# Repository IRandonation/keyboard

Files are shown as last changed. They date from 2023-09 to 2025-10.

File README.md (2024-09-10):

# keyboard

try to design my personal keyboard

## ROCK NUMBER KWYBOARD

### PCB design

###### ---------------2023.6.10--------------

As mt first keyboard, i try to design a small keyborad for number zone.
Not as same as regular keyboard, i tend to use stm32 instead of atmage.

###### ---------------2024.9.9----------------

Finish my PCB and successfully weld that. But what is so stupid is that i welded my shaft seat upside down, which led to i cannot put my shaft to my PCB. So i have to correct this problem.

###### ---------------2024.9.10---------------

i found a promblem that when you try to connnet stm32f103 to your computer by type-c, you should use two 5.1kR resistances in CC pin, which help computer to recognize the chip. For this version i did not use these resistance. Besides, you should use a 1.5k, which connects between D+ and 3.3V
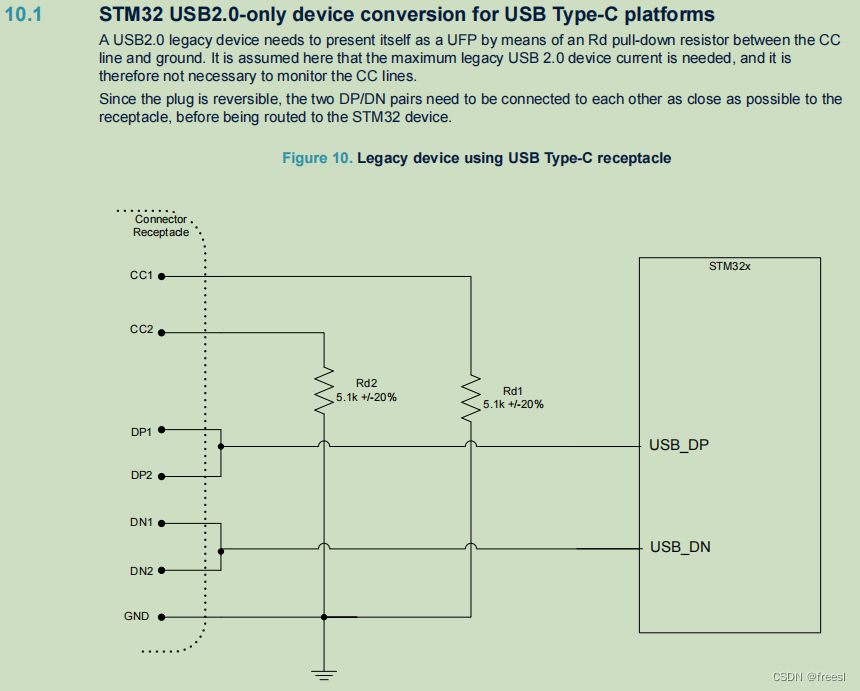
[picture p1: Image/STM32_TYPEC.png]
STM32-TYPEC

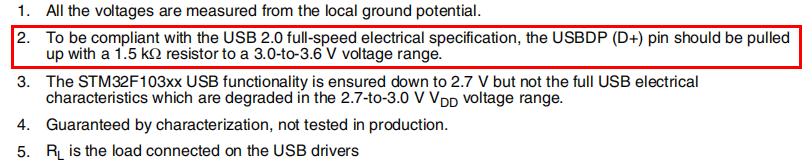
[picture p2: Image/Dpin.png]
STM32-TYPEC-D+


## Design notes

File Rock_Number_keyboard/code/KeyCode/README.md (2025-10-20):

# Rock Number Keyboard / KeyCode 项目说明

本仓库为基于 STM32F4（STM32F407）与 USB HID 的矩阵键盘固件工程，提供矩阵键盘扫描、按键映射与通过 USB 作为键盘设备向主机发送按键的能力。工程主要使用 STM32 HAL 库，配套 Keil MDK-ARM 工程文件，并保留 STM32CubeMX 的 `KeyCode.ioc` 以便后续外设与引脚配置维护。

## 功能特性
- 矩阵键盘扫描与去抖动处理（`Core/Src/matrix_keyboard.c`）
- 按键映射与事件上报（可在 `matrix_keyboard.h/.c` 中调整）
- 通过 USB 设备枚举为键盘（HID），向主机发送按键报告
- **WS2812 RGB背光系统**（`Core/Src/ws2812.c`）
  - 6种背光模式：关闭、静态、呼吸、彩虹、按键响应、波浪
  - Num Lock长按切换模式，亮度可调
  - DMA驱动，高效稳定的LED控制
  - 实时动态效果处理
- 采用 STM32 HAL 驱动与 ST 官方 USB Device Library

## 目录结构
- `Core/Inc` / `Core/Src`：应用入口与业务逻辑
  - `main.c`：程序入口与系统初始化
  - `matrix_keyboard.h/.c`：矩阵键盘扫描、映射与接口
  - `ws2812.h/.c`：WS2812 RGB背光驱动与多模式控制
  - `tim.c/h`：定时器配置（TIM4用于WS2812 PWM+DMA）
  - `gpio.c/h`：GPIO 引脚初始化
  - `stm32f4xx_it.c/h`：中断处理（包含DMA中断）
- `USB_DEVICE`：USB 设备层
  - `App/usb_device.*`：USB 栈初始化入口
  - `App/usbd_desc.*`：USB 设备描述符（VID/PID、字符串等）
  - `Target/usbd_conf.*`：与 HAL 的适配层
- `Drivers/STM32F4xx_HAL_Driver`、`Drivers/CMSIS`：HAL 与 CMSIS 依赖
- `MDK-ARM`：Keil uVision 工程（`KeyCode.uvprojx`、`KeyCode.uvoptx`）与启动文件
- `.eide`、`.vscode`：EIDE 与 VS Code 相关配置（可选）
- `KeyCode.ioc`：CubeMX 工程文件（用于生成/维护外设与引脚配置）

## 开发环境
- 工具链：
  - Keil MDK-ARM（推荐，已提供完整工程）
  - 或 STM32CubeIDE（可依据 `KeyCode.ioc` 重新生成工程后迁移代码）
- 依赖：
  - STM32F4 HAL Driver（已包含在 `Drivers` 目录）
  - ST USB Device Library（`Middlewares/ST/STM32_USB_Device_Library`）
- 目标芯片：STM32F407（参考启动文件 `startup_stm32f407xx.s`）

## 快速开始
1. 使用 Keil uVision 打开 `MDK-ARM/KeyCode.uvprojx`。
2. 连接硬件：
   - STM32F407 开发板 + 矩阵键盘
   - WS2812 LED灯带连接到 PB6 (TIM4_CH1)
   - USB设备口接PC
3. 选择正确的目标、下载器与时钟设置后，编译并烧录固件。
4. 上电后设备将枚举为 USB 键盘；按下矩阵键盘上的按键，主机应能收到对应键值。
5. **背光控制**：长按 Num Lock 键（>1秒）可切换背光模式。

## 配置说明
- 键盘矩阵与引脚：
  - 在 `Core/Inc/matrix_keyboard.h` 与 `Core/Src/gpio.c` 中查看/调整行列引脚定义与模式（上拉/输出等）。
  - 根据实际硬件连线更新对应的 GPIO 端口与引脚。
- 按键映射：
  - 在 `matrix_keyboard.c` 中维护从（行、列）到键值的映射表；可根据需求映射为数字、功能键或自定义 HID 键码。
- **WS2812背光配置**：
  - 在 `Core/Inc/ws2812.h` 中配置LED数量（`WS2812_LED_COUNT`）和引脚连接
  - 默认使用 PB6 (TIM4_CH1) 作为数据输出引脚
  - 可在 `ws2812.c` 中调整颜色、亮度、效果速度等参数
  - 支持的背光模式：OFF、STATIC、BREATHING、RAINBOW、KEY_REACTIVE、WAVE
- USB 描述符：
  - 在 `USB_DEVICE/App/usbd_desc.c` 中配置 `VID/PID`、制造商/产品字符串；如需产品化请申请合法 VID/PID。
  - HID 报告描述符位于 USB HID 类实现中（通常在 USB 类文件或键盘报告生成处维护）。如需修改键盘布局或支持组合键，需同步调整报告格式与发送逻辑。

## 运行时行为
- 系统初始化后启动矩阵扫描定时逻辑（或在主循环中轮询）。
- 按键状态变化将转换为 HID 报告并通过 USB 发送至主机。
- **WS2812背光系统**：
  - 系统启动时初始化为静态白色背光模式，亮度50%
  - 主循环中持续调用 `WS2812_ProcessEffects()` 处理动态效果
  - Num Lock键长按检测（>1秒）触发模式切换
  - 按键事件同步通知背光系统，实现按键响应效果
  - DMA传输完成后自动更新LED显示
- 去抖动、长按/重复等策略可在 `matrix_keyboard.c` 中扩展。

## 常用开发建议
- 使用 CubeMX 调整外设或引脚：
  - 打开 `KeyCode.ioc`，修改后仅生成驱动层，避免覆盖 `matrix_keyboard.*` 与业务逻辑文件。
- VS Code/EIDE：
  - 仓库提供 `.vscode/tasks.json` 与 `.eide`，可参考进行编译或工程管理（以实际环境为准）。

## 故障排查
- 设备未能枚举为键盘：
  - 检查 USB 供电与 D+/D- 连接；确认 `usb_device_init()` 被调用。
  - 确认 `usbd_conf.c` 与时钟配置（`system_stm32f4xx.c`）正确。
- 按键无响应或乱码：
  - 校验矩阵行列引脚配置与上拉/下拉设置；检查去抖动逻辑。
  - 检查按键映射是否与 HID 报告格式一致。
- **WS2812背光问题**：
  - LED不亮：检查 PB6 引脚连接，确认 TIM4 时钟使能，检查DMA配置
  - 颜色异常：确认WS2812时序参数（0码、1码脉宽），检查供电电压（5V推荐）
  - 模式切换无效：确认Num Lock键映射正确，检查长按检测逻辑
  - 效果卡顿：检查主循环中 `WS2812_ProcessEffects()` 调用频率
  - DMA传输错误：确认DMA中断处理函数 `DMA1_Stream0_IRQHandler()` 正确实现

## 示例电路连接图

### 矩阵键盘连接
- 行（输出，推挽，高速）：`GPIOE` — `PE15(R0)`, `PE14(R1)`, `PE13(R2)`, `PE12(R3)`, `PE11(R4)`。
- 列（输入，下拉）：`GPIOA` — `PA7(C0)`, `PA6(C1)`, `PA5(C2)`, `PA4(C3)`。
- 连接方式：每个交点为一个按键开关，可选串接二极管（建议 `1N4148`）以减少按键串扰与"鬼键"。推荐二极管方向：`Row →|— Diode —→ Column`（行拉高时，闭合将列拉至高电平）。

### WS2812 LED背光连接
- **数据线**：PB6 (TIM4_CH1) → WS2812 DIN
- **电源**：5V → WS2812 VDD，GND → WS2812 GND
- **布局建议**：LED按键盘布局排列，每个按键对应一个LED
- **信号完整性**：数据线尽量短，可加33Ω-100Ω串联电阻减少反射

```
Columns:   C0(PA7)    C1(PA6)    C2(PA5)    C3(PA4)
Rows
R0(PE15) ──[SW]───────[SW]───────[SW]───────[SW]
R1(PE14) ──[SW]───────[SW]───────[SW]───────(空)
R2(PE13) ──[SW]───────[SW]───────[SW]───────[SW]
R3(PE12) ──[SW]───────[SW]───────[SW]───────(空)
R4(PE11) ──[SW]───────[SW]───────[SW]───────(空)
```

说明：行由固件轮询依次拉高，列为下拉输入；当某行与某列的开关闭合时，该列读取为高电平，触发对应按键事件。

## 按键映射表（与 `matrix_keyboard.c` 保持一致）
- 行索引与引脚：`R0=PE15`, `R1=PE14`, `R2=PE13`, `R3=PE12`, `R4=PE11`
- 列索引与引脚：`C0=PA7`, `C1=PA6`, `C2=PA5`, `C3=PA4`

| 行(R) | 列(C) | 行引脚 | 列引脚 | HID 键码 | 说明 |
|---|---|---|---|---|---|
| R0 | C0 | PE15 | PA7 | `0x53` | Num Lock |
| R0 | C1 | PE15 | PA6 | `0x54` | Keypad `/` |
| R0 | C2 | PE15 | PA5 | `0x55` | Keypad `*` |
| R0 | C3 | PE15 | PA4 | `0x56` | Keypad `-` |
| R1 | C0 | PE14 | PA7 | `0x59` | Keypad `1` |
| R1 | C1 | PE14 | PA6 | `0x5A` | Keypad `2` |
| R1 | C2 | PE14 | PA5 | `0x5B` | Keypad `3` |
| R1 | C3 | PE14 | PA4 | `0x00` | 空位 |
| R2 | C0 | PE13 | PA7 | `0x5C` | Keypad `4` |
| R2 | C1 | PE13 | PA6 | `0x5D` | Keypad `5` |
| R2 | C2 | PE13 | PA5 | `0x5E` | Keypad `6` |
| R2 | C3 | PE13 | PA4 | `0x57` | Keypad `+` |
| R3 | C0 | PE12 | PA7 | `0x5F` | Keypad `7` |
| R3 | C1 | PE12 | PA6 | `0x60` | Keypad `8` |
| R3 | C2 | PE12 | PA5 | `0x61` | Keypad `9` |
| R3 | C3 | PE12 | PA4 | `0x00` | 空位 |
| R4 | C0 | PE11 | PA7 | `0x62` | Keypad `0` |
| R4 | C1 | PE11 | PA6 | `0x63` | Keypad `.` |
| R4 | C2 | PE11 | PA5 | `0x58` | Keypad `Enter` |
| R4 | C3 | PE11 | PA4 | `0x00` | 空位 |

提示：如需更改布局或引脚，请同步更新 `Core/Src/matrix_keyboard.c` 中的 `ROW_Port/ROW_Pin`、`COL_Port/COL_Pin` 与 `Key_Map`，并确保 USB HID 报告的生成逻辑能够正确处理新的键码。

## WS2812 背光模式详细说明

### 支持的背光模式

1. **OFF模式** - 所有LED关闭，节能模式
2. **STATIC模式** - 静态白色背光，适合日常使用
3. **BREATHING模式** - 呼吸灯效果，亮度平滑变化（周期约2秒）
4. **RAINBOW模式** - 彩虹色循环效果，色彩丰富动态
5. **KEY_REACTIVE模式** - 按键响应模式，按下时LED亮起，释放后渐变熄灭
6. **WAVE模式** - 青色波浪效果，从左到右流动

### 模式切换操作

- **切换方法**：长按 Num Lock 键超过1秒
- **切换顺序**：OFF → STATIC → BREATHING → RAINBOW → KEY_REACTIVE → WAVE → OFF（循环）
- **状态保持**：模式切换后立即生效，重启后恢复默认STATIC模式

### 技术参数

- **LED数量**：20个（可在 `ws2812.h` 中的 `WS2812_LED_COUNT` 修改）
- **默认亮度**：50%（可通过 `WS2812_SetBrightness()` 调节0-100%）
- **更新频率**：主循环调用，约1kHz
- **DMA传输**：使用DMA1 Stream0，自动传输24位RGB数据
- **时序标准**：符合WS2812B规范（T0H=0.4μs, T1H=0.8μs, T0L=0.85μs, T1L=0.45μs）

### API接口说明

```c
// 模式控制
void WS2812_SetMode(WS2812_Mode mode);          // 设置背光模式
WS2812_Mode WS2812_GetMode(void);               // 获取当前模式
void WS2812_NextMode(void);                     // 切换到下一个模式

// 亮度控制
void WS2812_SetBrightness(uint8_t brightness);  // 设置亮度(0-100)
uint8_t WS2812_GetBrightness(void);             // 获取当前亮度

// 效果处理
void WS2812_ProcessEffects(void);               // 处理动态效果（主循环调用）
void WS2812_OnKeyPress(uint8_t row, uint8_t col);   // 按键按下事件
void WS2812_OnKeyRelease(uint8_t row, uint8_t col); // 按键释放事件

// 颜色控制
void WS2812_SetColor(uint16_t led_index, uint8_t r, uint8_t g, uint8_t b);
void WS2812_SetAllColor(uint8_t r, uint8_t g, uint8_t b);
void WS2812_Update(void);                       // 更新LED显示
```

### 自定义开发

如需添加新的背光模式或修改现有效果：

1. 在 `ws2812.h` 中的 `WS2812_Mode` 枚举添加新模式
2. 在 `ws2812.c` 的 `WS2812_ProcessEffects()` 函数中添加对应的处理逻辑
3. 根据需要调整颜色、速度、亮度等参数
4. 可参考现有模式的实现方式，使用定时器和数学函数创建动态效果

## 许可证
- 本项目未显式声明整体许可证；第三方依赖（HAL/USB 库）遵循各自目录下的许可文件。
- 如需开源或商用，请添加或遵循相应的许可证与合规要求。

## 贡献
- 欢迎通过 Issue 或 PR 提交改进建议与修复。
- 提交前请尽量维持代码风格与目录结构一致性。

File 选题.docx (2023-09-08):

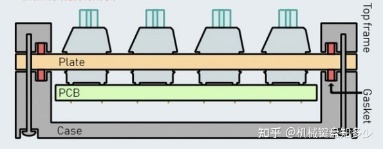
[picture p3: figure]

键盘配色：深空灰配白，铝坨坨

配重：正常

键盘结构：Gasket（比较难特别是对于硅胶垫）/top结构

铭牌：暂定

键帽：白、蓝、黑、灰

轴体：热插拔

定位板：铝定（声音沉闷）

PCB：立创定制

数据线：航插线或三模

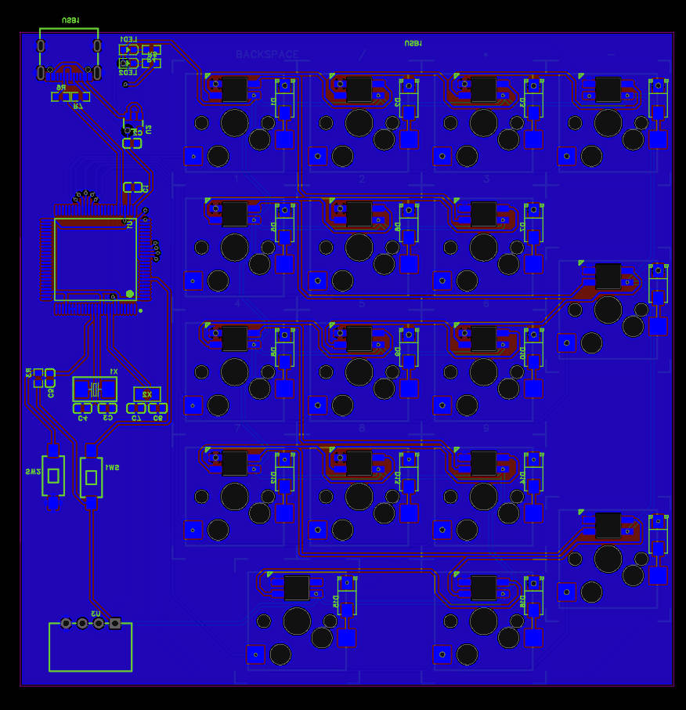
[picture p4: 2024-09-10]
Image/PCB.jpg

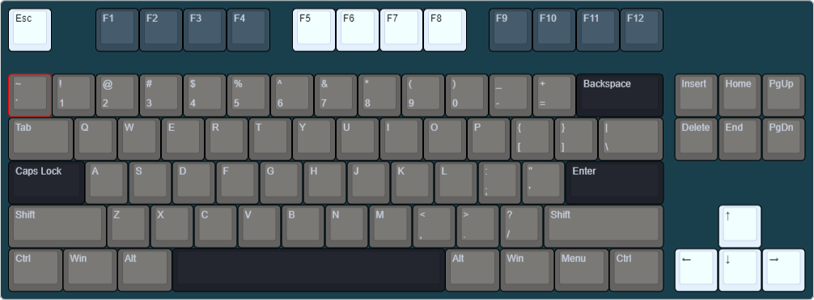
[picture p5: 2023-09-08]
Galaxy_87Keyboard/keyboard-layout.png

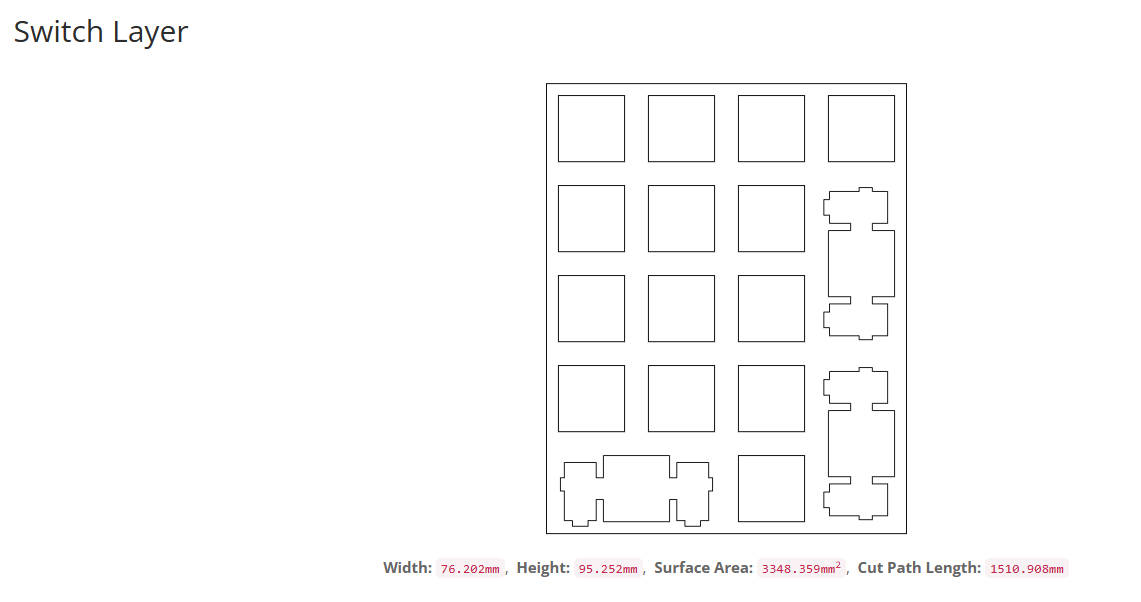
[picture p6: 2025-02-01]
Rock_Number_keyboard/keyboard.jpg

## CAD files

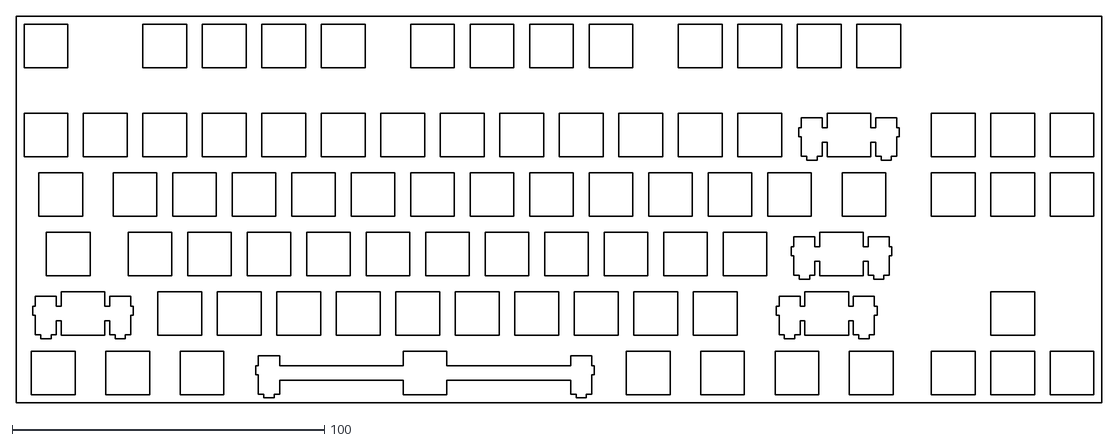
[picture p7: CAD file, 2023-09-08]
Galaxy_87Keyboard/Keyboard.dxf
347.7 x 123.8

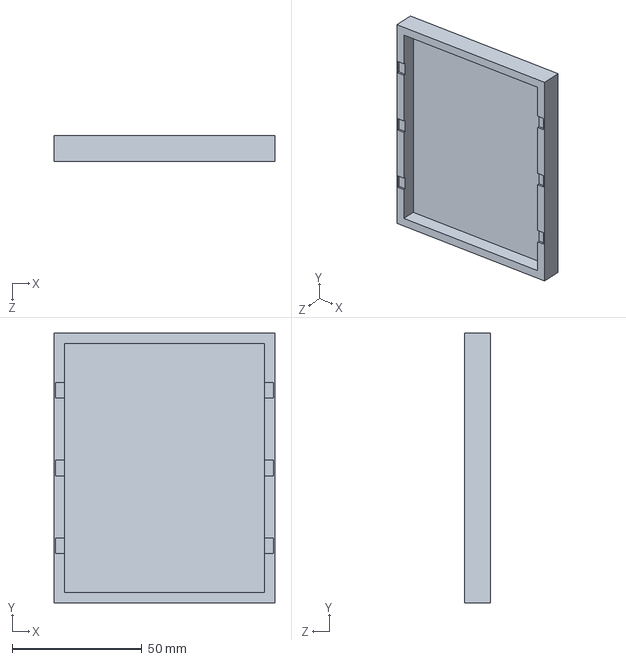
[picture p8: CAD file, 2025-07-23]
Rock_Number_keyboard/3D/外壳.SLDPRT
85.1 x 104.2 x 10.0 mm

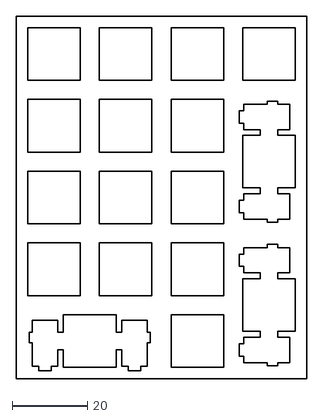
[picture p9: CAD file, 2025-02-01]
Rock_Number_keyboard/Rock_Number_pcb.dxf
77.1 x 96.2

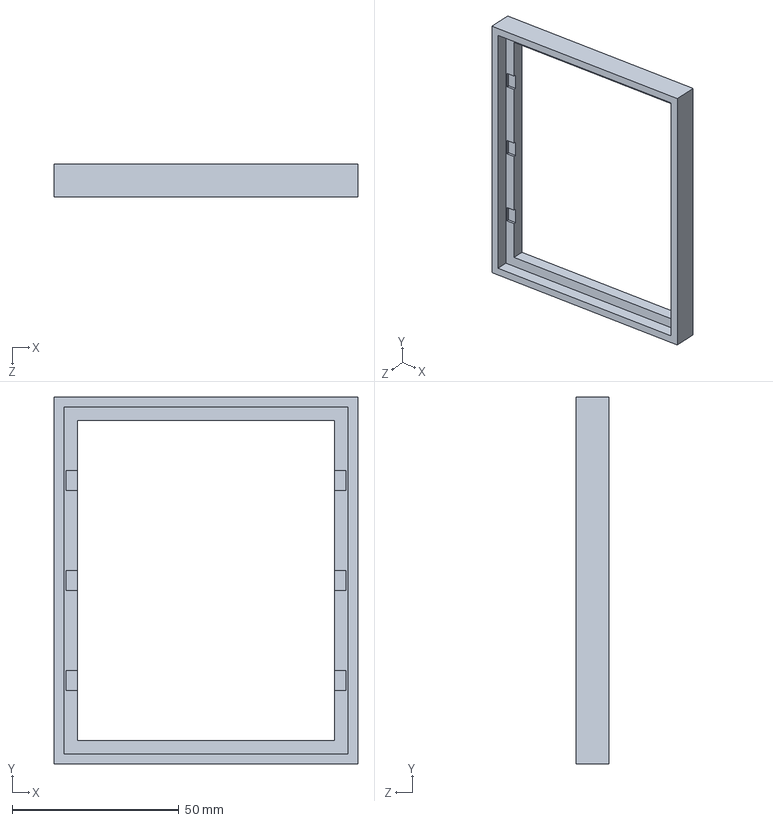
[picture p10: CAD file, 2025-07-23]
Rock_Number_keyboard/3D/上盖.SLDPRT
91.1 x 110.2 x 10.0 mm

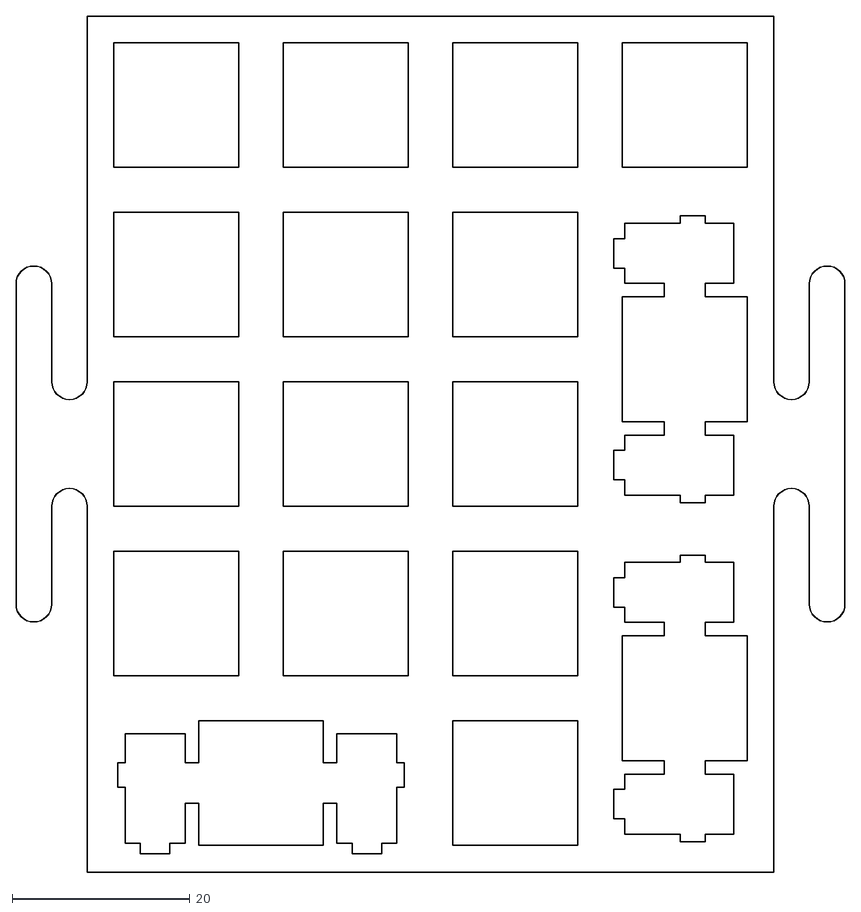
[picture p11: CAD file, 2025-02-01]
Rock_Number_keyboard/Rock_Number.dxf
93.1 x 96.2

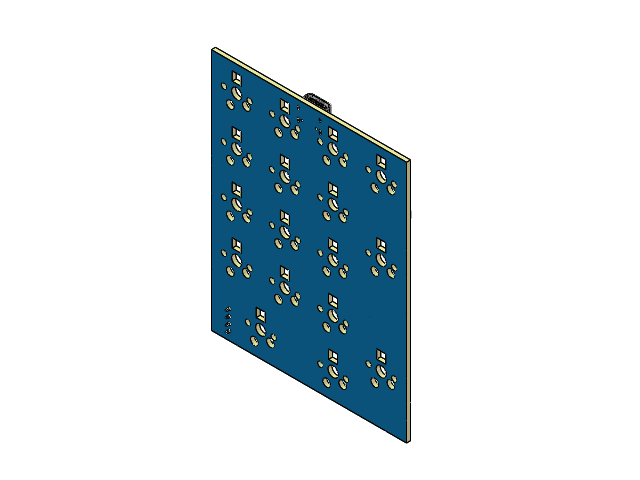
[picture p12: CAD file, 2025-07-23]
Rock_Number_keyboard/3D/PCB/3D_Rock_Number_Keyboard_2025-05-22.SLDASM
eauz-Board
eauz-C1-C0603 x 6
eauz-X1-OSC-SMD_L5.0-W3.2
eauz-SW1-SW-SMD_L6.0-W3.3-LS8.0 x 2
eauz-D1-SOD-123_L2.8-W1.6-LS3.7-RD x 17
eauz-U2-LQFP-100_L14.0-W14.0-P0.50-LS16.0-BL

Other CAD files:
Rock_Number_keyboard/3D/PCB/eauz-R1-R0603.SLDASM
Rock_Number_keyboard/3D/PCB/eauz-R5-R0603.SLDASM
Rock_Number_keyboard/3D/PCB/eauz-H1-HDR-TH_4P-P2.54-V-F.SLDASM
Rock_Number_keyboard/3D/PCB/eauz-USB1-USB-C-SMD_KH-TYPE-C-16P.SLDASM
Rock_Number_keyboard/3D/PCB/eauz-R3-R0603.SLDASM
Rock_Number_keyboard/3D/PCB/eauz-R6-R0603.SLDASM
Rock_Number_keyboard/3D/PCB/eauz-LED1-LED0603-RD_GREEN.SLDASM
Rock_Number_keyboard/3D/PCB/eauz-R7-R0603.SLDASM
Rock_Number_keyboard/3D/PCB/eauz-R4-R0603.SLDASM
Rock_Number_keyboard/3D/PCB/eauz-U1-SOT-23-5_L2.9-W1.6-P0.95-LS2.8-BR.SLDASM
Rock_Number_keyboard/3D/PCB/eauz-R2-R0603.SLDASM
Rock_Number_keyboard/3D/PCB/eauz-Board.SLDPRT
Galaxy_87Keyboard/Keyboard.dwg
Rock_Number_keyboard/3D/Board.SLDPRT
Rock_Number_keyboard/3D/PCB/COMPOUND.SLDPRT
Rock_Number_keyboard/3D/PCB/COMPOUND_2.SLDPRT
Rock_Number_keyboard/3D/PCB/COMPOUND_3.SLDPRT
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

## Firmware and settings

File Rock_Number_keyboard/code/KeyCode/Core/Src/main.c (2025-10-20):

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
/* Includes ------------------------------------------------------------------*/
#include "main.h"
#include "tim.h"
#include "usb_device.h"
#include "gpio.h"
#include "ws2812.h"

/* USER CODE BEGIN Includes */
#include "usbd_hid.h"
#include "matrix_keyboard.h"  // 包含矩阵键盘头文件
#include <stdbool.h>

/* USER CODE END Includes */


/* USER CODE BEGIN PV */
extern USBD_HandleTypeDef hUsbDeviceFS;
// HID报告结构体（兼容标准键盘）
#pragma pack(push, 1)
typedef struct {
    uint8_t modifier;   // 修饰键
    uint8_t reserved;   // 保留
    uint8_t keycode[6]; // 最多6键
} HID_KeyboardReport;
#pragma pack(pop)

// 添加键盘报告变量
static HID_KeyboardReport keyboard_report;

// 发送HID报告
void Send_HID_Report(uint8_t keycode) {
    HID_KeyboardReport report = {0};

    if (keycode != 0) {
        report.keycode[0] = keycode; // 单键按下
    }

    // 通过USB发送报告
    USBD_HID_SendReport(&hUsbDeviceFS, (uint8_t*)&report, sizeof(report));
    HAL_Delay(20); // 等待数据发送完成
}

/* USER CODE END PV */

void SystemClock_Config(void);
/**
  * @brief  The application entry point.
  * @retval int
  */
int main(void)
{
  /* MCU Configuration--------------------------------------------------------*/

  /* Reset of all peripherals, Initializes the Flash interface and the Systick. */
  HAL_Init();

  /* Configure the system clock */
  SystemClock_Config();

  /* Initialize all configured peripherals */
  MX_GPIO_Init();
  MX_USB_DEVICE_Init();
  MX_TIM3_Init();
  MX_TIM4_Init();
  /* USER CODE BEGIN 2 */
  WS2812_Init();
  HAL_TIM_Base_Start_IT(&htim3);
  MatrixKeyboard_Init();
  /* 定义一个缓冲区来接收按键事件 */
   KeyEvent key_events_buffer[MAX_PRESSED_KEYS];
   
  // 用于标记HID报告是否需要更新并发送
  bool report_needs_update = false;

  // 清空初始的键盘报告
  memset(&keyboard_report, 0, sizeof(keyboard_report));
  
  // 模式切换相关变量
  static uint32_t num_lock_press_time = 0;
  static bool num_lock_long_press_handled = false;
  
  // 设置默认背光模式
  WS2812_SetMode(WS2812_MODE_STATIC);
  WS2812_SetBrightness(50);
  
  /* USER CODE END 2 */

  /* Infinite loop */
  /* USER CODE BEGIN WHILE */
  while (1)
  {
    // 1. 从事件队列获取按键事件（由TIM3中断产生）
        uint8_t event_count = 0;
        for (uint8_t i = 0; i < MAX_PRESSED_KEYS; i++) {
            if (MatrixKeyboard_PopEvent(&key_events_buffer[i])) {
                event_count++;
            } else {
                break;
            }
        }

        // 2. 如果有任何事件发生，则处理它们
        if (event_count > 0) {
            // 标记报告需要更新
            report_needs_update = true;

            for (uint8_t i = 0; i < event_count; i++) {
                KeyEvent event = key_events_buffer[i];

                // 检查是否是Num Lock键 (ROW0, COL0, 键码0x53)
                bool is_num_lock = (event.row == 0 && event.col == 0 && event.key_code == 0x53);

                if (event.event == KEY_EVENT_PRESS) 
                {
                    if (is_num_lock) {
                        num_lock_press_time = HAL_GetTick();
                        num_lock_long_press_handled = false;
                    }
                    
                    // 按下事件: 将键码添加到HID报告中
                    // 查找一个空位来存放新的键码
                    for (int j = 0; j < 6; j++) {
                        if (keyboard_report.keycode[j] == 0x00) {
                            keyboard_report.keycode[j] = event.key_code;
                            break;
                        }
                    }
                    
                    // 通知WS2812按键按下事件
                    WS2812_OnKeyPress(event.row, event.col);
                }
                else if (event.event == KEY_EVENT_LONG_PRESS) 
                {
                    if (is_num_lock && !num_lock_long_press_handled) {
                        // Num Lock长按切换背光模式
                        WS2812_NextMode();
                        num_lock_long_press_handled = true;
                        
                        // 不发送Num Lock的HID报告，避免切换系统Num Lock状态
                        continue;
                    }
                    
                    // 其他键的长按处理
                    for (int j = 0; j < 6; j++) {
                        if (keyboard_report.keycode[j] == 0x00) {
                            keyboard_report.keycode[j] = event.key_code;
                            break;
                        }
                    }
                    
                    WS2812_OnKeyPress(event.row, event.col);
                }
                else if (event.event == KEY_EVENT_REPEAT) 
                {
                    // 连发事件处理
                    if (!is_num_lock) {  // Num Lock不处理连发
                        for (int j = 0; j < 6; j++) {
                            if (keyboard_report.keycode[j] == 0x00) {
                                keyboard_report.keycode[j] = event.key_code;
                                break;
                            }
                        }
                    }
                }
                else if (event.event == KEY_EVENT_RELEASE) 
                {
                    if (is_num_lock) {
                        uint32_t press_duration = HAL_GetTick() - num_lock_press_time;
                        
                        // 如果是短按且没有处理过长按，则正常发送Num Lock
                        if (press_duration < 1000 && !num_lock_long_press_handled) {
                            // 正常的Num Lock短按，发送HID报告
                        } else {
                            // 长按释放，不发送HID报告
                            continue;
                        }
                    }
                    
                    // 释放事件: 从HID报告中移除该键码
                    for (int j = 0; j < 6; j++) {
                        if (keyboard_report.keycode[j] == event.key_code) {
                            keyboard_report.keycode[j] = 0x00; // 清除
                        }
                    }
                    
                    // 通知WS2812按键释放事件
                    WS2812_OnKeyRelease(event.row, event.col);
                }
            }
        }

        // 3. 检查是否需要发送HID报告
        // 只有在按键状态变化时才发送，这比每次循环都发送更高效
        if (report_needs_update) {
            // 清除更新标记
            report_needs_update = false;

            // 发送HID报告（仅在状态变化时发送）
            USBD_HID_SendReport(&hUsbDeviceFS, (uint8_t*)&keyboard_report, sizeof(keyboard_report));
            
            // 为了处理按键释放，我们需要在发送完有效报告后，
            // 立即发送一个全零的 "释放" 报告。
            // 但更好的做法是让PC自己处理按键释放。
            // 只有当所有按键都释放时，我们才需要发送一个全零报告。
            // 我们可以通过检查 keyboard_report 是否全为0来判断。
            bool all_keys_released = true;
            for(int j=0; j<6; j++) {
                if (keyboard_report.keycode[j] != 0) {
                    all_keys_released = false;
                    break;
                }
            }

            // 如果所有按键都释放了，并且上一次不是全零报告，则发送一次全零报告
            if(all_keys_released){
                 // 稍作延时，确保上一个报告被PC接收
                 // HAL_Delay(1); 
                 // 发送全零报告
                 memset(&keyboard_report, 0, sizeof(keyboard_report));
                 USBD_HID_SendReport(&hUsbDeviceFS, (uint8_t*)&keyboard_report, sizeof(keyboard_report));
            }
        }

        // 处理WS2812动态效果
        WS2812_ProcessEffects();
        
        // 更新 WS2812 LED 如果有变化
        if (report_needs_update) {
            WS2812_Update();
        }
        
        // 可以在这里加一个非常短的延时，以降低CPU使用率，但不是必须的
        // HAL_Delay(1); 
    }
    /* USER CODE END WHILE */

}

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
/* USER CODE BEGIN 4 */
void HAL_TIM_PeriodElapsedCallback(TIM_HandleTypeDef *htim)
{
  if (htim->Instance == TIM3) {
    MatrixKeyboard_ScanStep_ISR();
  }
}
/* USER CODE END 4 */
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


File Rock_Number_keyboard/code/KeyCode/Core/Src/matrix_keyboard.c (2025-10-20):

#include "matrix_keyboard.h"
#include <string.h>
#include <stdbool.h>

// --- GPIO 配置 (与您原来的代码一致) ---
static GPIO_TypeDef* ROW_Port[ROW_NUM] = {GPIOE, GPIOE, GPIOE, GPIOE, GPIOE};
static uint16_t ROW_Pin[ROW_NUM] = {GPIO_PIN_15, GPIO_PIN_14, GPIO_PIN_13, GPIO_PIN_12, GPIO_PIN_11};

static GPIO_TypeDef* COL_Port[COL_NUM] = {GPIOA, GPIOA, GPIOA, GPIOA};
static uint16_t COL_Pin[COL_NUM] = {GPIO_PIN_7, GPIO_PIN_6, GPIO_PIN_5, GPIO_PIN_4};

// --- 按键映射表 (与您原来的代码一致) ---
static const uint8_t Key_Map[ROW_NUM][COL_NUM] = {
    /* ROW0 */ {0x53, 0x54, 0x55, 0x56}, // num,/,*,-
    /* ROW1 */ {0x59, 0x5A, 0x5B, 0x00}, // 7,8,9 (注意，我根据小键盘布局调整了这里，原代码可能是1,2,3)
    /* ROW2 */ {0x5C, 0x5D, 0x5E, 0x57}, // 4,5,6,+
    /* ROW3 */ {0x5F, 0x60, 0x61, 0x00}, // 1,2,3 (原代码可能是7,8,9)
    /* ROW4 */ {0x62, 0x63, 0x58, 0x00}  // 0,.,enter
};

// --- 内部状态定义 ---
typedef enum {
    STATE_IDLE,       // 0. 空闲（已释放）
    STATE_DEBOUNCE,   // 1. 消抖
    STATE_PRESSED,    // 2. 已按下
    STATE_LONG_PRESS  // 3. 长按
} KeyState;

// --- 静态变量 ---
// 存储每个按键的独立状态
static struct {
    KeyState state;       // 当前状态
    uint32_t timer;       // 计时器，用于消抖和长按判断
} s_key_fsm[ROW_NUM][COL_NUM]; // FSM: Finite State Machine

// 积分消抖计数器
static uint8_t s_int_cnt[ROW_NUM][COL_NUM];
#define INT_PRESS_THRESH    5   // 达到该积分认定为按下
#define INT_RELEASE_THRESH  2   // 下降到该积分认定为释放

// 上次处理的时间戳
static uint32_t s_last_process_tick = 0;

// ---- 事件队列（ISR生产，主循环消费） ----
#define EVENT_QUEUE_SIZE 32
static volatile uint8_t s_evt_head = 0;
static volatile uint8_t s_evt_tail = 0;
static KeyEvent s_evt_queue[EVENT_QUEUE_SIZE];

static inline void push_event_isr(uint8_t r, uint8_t c, KeyEventType type)
{
    uint8_t next_head = (uint8_t)((s_evt_head + 1) % EVENT_QUEUE_SIZE);
    if (next_head == s_evt_tail) {
        // 队列满，丢弃最旧一个，释放一格
        s_evt_tail = (uint8_t)((s_evt_tail + 1) % EVENT_QUEUE_SIZE);
    }
    s_evt_queue[s_evt_head].key_code = Key_Map[r][c];
    s_evt_queue[s_evt_head].row = r;
    s_evt_queue[s_evt_head].col = c;
    s_evt_queue[s_evt_head].event = type;
    s_evt_head = next_head;
}

bool MatrixKeyboard_PopEvent(KeyEvent* out_event)
{
    if (s_evt_tail == s_evt_head) return false; // 空
    *out_event = s_evt_queue[s_evt_tail];
    s_evt_tail = (uint8_t)((s_evt_tail + 1) % EVENT_QUEUE_SIZE);
    return true;
}

// 定时器ISR时间基准（ms）
static volatile uint32_t s_isr_tick_ms = 0;

// --- 函数实现 ---

/**
 * @brief 初始化函数 (与您的版本基本相同，只是更整洁)
 */
void MatrixKeyboard_Init(void) {
    GPIO_InitTypeDef GPIO_InitStruct = {0};

    // 1. 使能时钟
    __HAL_RCC_GPIOE_CLK_ENABLE();
    __HAL_RCC_GPIOA_CLK_ENABLE();

    // 2. 初始化行线 (推挽输出)
    GPIO_InitStruct.Mode = GPIO_MODE_OUTPUT_PP;
    GPIO_InitStruct.Pull = GPIO_NOPULL;
    GPIO_InitStruct.Speed = GPIO_SPEED_FREQ_HIGH;
    for (uint8_t i = 0; i < ROW_NUM; i++) {
        HAL_GPIO_WritePin(ROW_Port[i], ROW_Pin[i], GPIO_PIN_RESET);
        GPIO_InitStruct.Pin = ROW_Pin[i];
        HAL_GPIO_Init(ROW_Port[i], &GPIO_InitStruct);
    }

    // 3. 初始化列线 (下拉输入)
    GPIO_InitStruct.Mode = GPIO_MODE_INPUT;
    GPIO_InitStruct.Pull = GPIO_PULLDOWN;
    for (uint8_t i = 0; i < COL_NUM; i++) {
        GPIO_InitStruct.Pin = COL_Pin[i];
        HAL_GPIO_Init(COL_Port[i], &GPIO_InitStruct);
    }
    
    // 4. 初始化所有按键状态机
    for (uint8_t r = 0; r < ROW_NUM; r++) {
        for (uint8_t c = 0; c < COL_NUM; c++) {
            s_key_fsm[r][c].state = STATE_IDLE;
            s_key_fsm[r][c].timer = 0;
            s_int_cnt[r][c] = 0;
        }
    }
}
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

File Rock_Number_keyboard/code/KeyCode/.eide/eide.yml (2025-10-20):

version: "4.1"
name: KeyCode
type: ARM
deviceName: STM32F407VETx
packDir: .pack/Keil/STM32F4xx_DFP.2.14.0
srcDirs: []
virtualFolder:
  name: <virtual_root>
  files: []
  folders:
    - name: Application
      files: []
      folders:
        - name: MDK-ARM
          files:
            - path: MDK-ARM/startup_stm32f407xx.s
          folders: []
        - name: User
          files: []
          folders:
            - name: Core
              files:
                - path: Core/Src/main.c
                - path: Core/Src/gpio.c
                - path: Core/Src/stm32f4xx_it.c
                - path: Core/Src/stm32f4xx_hal_msp.c
                - path: Core/Src/matrix_keyboard.c
                - path: Core/Src/system_stm32f4xx.c
                - path: Core/Src/tim.c
                - path: Core/Src/ws2812.c
              folders: []
            - name: USB_DEVICE
              files: []
              folders:
                - name: App
                  files:
                    - path: USB_DEVICE/App/usb_device.c
                    - path: USB_DEVICE/App/usbd_desc.c
                  folders: []
                - name: Target
                  files:
                    - path: USB_DEVICE/Target/usbd_conf.c
                  folders: []
    - name: Drivers
      files: []
      folders:
        - name: STM32F4xx_HAL_Driver
          files:
            - path: Drivers/STM32F4xx_HAL_Driver/Src/stm32f4xx_hal_pcd.c
            - path: Drivers/STM32F4xx_HAL_Driver/Src/stm32f4xx_hal_pcd_ex.c
            - path: Drivers/STM32F4xx_HAL_Driver/Src/stm32f4xx_ll_usb.c
            - path: Drivers/STM32F4xx_HAL_Driver/Src/stm32f4xx_hal_rcc.c
            - path: Drivers/STM32F4xx_HAL_Driver/Src/stm32f4xx_hal_rcc_ex.c
            - path: Drivers/STM32F4xx_HAL_Driver/Src/stm32f4xx_hal_flash.c
            - path: Drivers/STM32F4xx_HAL_Driver/Src/stm32f4xx_hal_flash_ex.c
            - path: Drivers/STM32F4xx_HAL_Driver/Src/stm32f4xx_hal_flash_ramfunc.c
            - path: Drivers/STM32F4xx_HAL_Driver/Src/stm32f4xx_hal_gpio.c
            - path: Drivers/STM32F4xx_HAL_Driver/Src/stm32f4xx_hal_dma_ex.c
            - path: Drivers/STM32F4xx_HAL_Driver/Src/stm32f4xx_hal_dma.c
            - path: Drivers/STM32F4xx_HAL_Driver/Src/stm32f4xx_hal_pwr.c
            - path: Drivers/STM32F4xx_HAL_Driver/Src/stm32f4xx_hal_pwr_ex.c
            - path: Drivers/STM32F4xx_HAL_Driver/Src/stm32f4xx_hal_cortex.c
            - path: Drivers/STM32F4xx_HAL_Driver/Src/stm32f4xx_hal.c
            - path: Drivers/STM32F4xx_HAL_Driver/Src/stm32f4xx_hal_exti.c
            - path: Drivers/STM32F4xx_HAL_Driver/Src/stm32f4xx_hal_tim.c
            - path: Drivers/STM32F4xx_HAL_Driver/Src/stm32f4xx_hal_tim_ex.c
          folders: []
        - name: CMSIS
          files:
            - path: Core/Src/system_stm32f4xx.c
          folders: []
    - name: Middlewares
      files: []
      folders:
        - name: USB_Device_Library
          files:
            - path: Middlewares/ST/STM32_USB_Device_Library/Core/Src/usbd_core.c
            - path: Middlewares/ST/STM32_USB_Device_Library/Core/Src/usbd_ctlreq.c
            - path: Middlewares/ST/STM32_USB_Device_Library/Core/Src/usbd_ioreq.c
            - path: Middlewares/ST/STM32_USB_Device_Library/Class/HID/Src/usbd_hid.c
          folders: []
dependenceList: []
outDir: build
miscInfo:
  uid: 93c739c956ab0b2426a27561f990bab1
targets:
  KeyCode:
    cppPreprocessAttrs:
      defineList:
        - USE_HAL_DRIVER
        - STM32F407xx
      incList:
        - .
        - USB_DEVICE/App
        - USB_DEVICE/Target
        - Drivers/STM32F4xx_HAL_Driver/Inc
        - Drivers/STM32F4xx_HAL_Driver/Inc/Legacy
        - Middlewares/ST/STM32_USB_Device_Library/Core/Inc
        - Middlewares/ST/STM32_USB_Device_Library/Class/HID/Inc
        - Drivers/CMSIS/Device/ST/STM32F4xx/Include
        - Drivers/CMSIS/Include
        - .cmsis/include
        - MDK-ARM/RTE/_KeyCode
        - Core/Inc
      libList: []
    excludeList: []
    toolchain: AC5
    toolchainConfigMap:
      AC5:
        archExtensions: ""
        cpuType: Cortex-M4
        floatingPointHardware: single
        options:
          version: 4
          afterBuildTasks: []
          asm-compiler: {}
          beforeBuildTasks: []
          c/cpp-compiler:
            CXX_FLAGS: --diag_suppress=1 --diag_suppress=1295
            C_FLAGS: --diag_suppress=1 --diag_suppress=1295
            c99-mode: true
            one-elf-section-per-function: true
            optimization: level-3
            warnings: all-warnings
          global:
            output-debug-info: enable
            use-microLIB: false
          linker:
            output-format: elf
            ro-base: ""
            rw-base: ""
            xo-base: ""
        scatterFilePath: ""
        storageLayout:
          RAM:
            - id: 1
              isChecked: true
              mem:
                size: "0x00020000"
                startAddr: "0x20000000"
              noInit: false
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

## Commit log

2023-09-08 my first upload
    [C0603.SLDASM, C0805.SLDASM, C0805_2.SLDASM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]
2024-09-09 小键盘打板完成
    [1mv2-C1.SLDASM, 1mv2-C2.SLDASM, 1mv2-C3.SLDASM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]
2025-02-01 已烧录HID
    [1mv2-C1.SLDASM, 1mv2-C2.SLDASM, 1mv2-C3.SLDASM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]
2025-02-01 修改了键盘映射
2025-03-24 完成小键盘算法，实现连按
2025-07-23 优化了按键问题，需要硬件验证
    [3D_Rock_Number_Keyboard_2024-12-27.SLDASM, 3D_Rock_Number_Keyboard_2025-05-22.SLDASM, Board.SLDPRT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]
2025-08-06 验证后完全没问题

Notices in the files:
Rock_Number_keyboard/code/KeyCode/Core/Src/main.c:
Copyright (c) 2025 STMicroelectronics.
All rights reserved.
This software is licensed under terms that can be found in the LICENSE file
